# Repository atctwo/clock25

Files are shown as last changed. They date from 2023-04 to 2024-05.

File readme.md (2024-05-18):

# clock25
A funky digital clock made out of an ESP32 and an RGB LED matrix panel!  This was created as a one-off personal project, but all the code and design files are included so I hope you find it useful or interesting!

Picture of the front of the clock

## Features
- tells the time in big rainbow digits
- gets time from the internet using NTP, and has an onboard RTC for keeping time without power
- the time can also be configured using physical onboard buttons 
- supports multiple "screens" which are basically apps
- the system and each screen can be configured with a web interface
    - available at a custom URL using mDNS: [clock25.local](http://clock25.local)
- the configuration is stored on an SD card so it can be edited manually without internet 
- adaptive brightness using ambient light sensor

Currently implemented screens are
- **Digital Clock Face**: also shows current temperature and humidity if an SHTC3 is connected
- **Weather Forecast**: gets weather from the internet
- **GIF Player**:  plays GIFs from SD card

# Implementation
## Hardware
### HUB75 RGB LED matrix
The clock has a big HUB75-style RGB LED matrix panel.  I used one which has 64x64 pixels.

### Custom PCB
Picture of the PCB

The project is driven by a custom PCB.  It holds:
- an ESP32-S3
- a PCF8523 RTC and a CR2032 coin cell battery holder
- a microSD card slot for storing the config file (and GIFs)
    - [an SHTC3 temperature sensor](https://www.adafruit.com/product/4636)
    - [a VEML7700 ambient light sensor](https://www.adafruit.com/product/4162)
    - [a APDS9960 gesture sensor](https://www.adafruit.com/product/3595)
- a 2x10 0.1" header for connecting to the HUB75 panel
- a USB-C connector for power (5V, 3A)
- onboard buttons for setting the time or changing screen

It's made with KiCad and located in the [pcb](./pcb/) folder.

### 3D Printed Frame
Picture of the back of the clock

The project includes a 3D printed frame which holds the matrix and the PCB.  Although the assembled version uses a JLCPCB box superglued onto a minimal frame because I didn't have enough filament to print the whole frame.  Note that the frame is designed to fit the obscure shape of the panel I have, if you want to make a clock25 you might need to modify the OpenSCAD file to fit the dimensions of your panel.

It's written in OpenSCAD using the [MCAD](https://github.com/openscad/MCAD) library, and is located in the [frame](./frame/) folder

## Software
### Configuration System
When screens are registered at compile time, they specify a series of key-value configuration items.  For example, the Digital Clock Face has a setting called "Rainbow Speed" which determines the speed of the rainbow text animation.  Values for each setting are stored in memory.  If an SD card is mounted, when settings are overwritten they are stored in a JSON file on the SD card.  When the clock boots it will load saved values from the SD card.  Each setting can be modified from the web interface without rebooting the clock.

A sample config JSON file is located at [extras/sd_layout/settings.json](extras/sd_layout/settings.json).

### Recommended SD card layout
Different parts of the system depend on some files being at specific locations on the SD card:
- Files for the Web Interface are hosted from /web/
- Weather Forecast expects weather icons to be located at /weather/
- GIF Player loads gifs from /gifs/

As such, there is a recommended layout for the SD card:

```plain
.
├── gifs
│   ├── example.gif
├── settings.json
├── weather
│   ├── 01d.bmp
│   ├── 01n.bmp
│   ├── ...
│   └── 50n.bmp
└── web
    ├── ball.css
    ├── index.css
    ├── index.html
    └── index.js
```

This layout is provided at [extras/sd_layout](extras/sd_layout/), so if you're setting up the SD card you can just copy the contents of this folder to the root of the SD.

### Web Interface
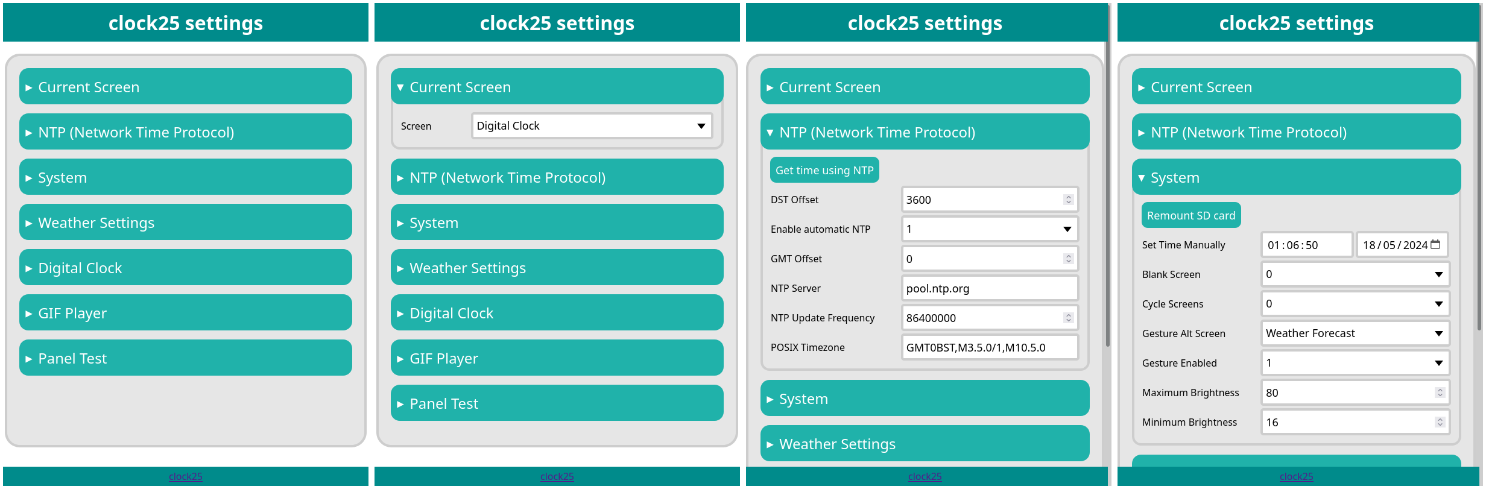
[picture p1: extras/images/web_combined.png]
Four screenshots of the web interface, showing the list of sections, and the screen, NTP, and system settings


When connected to a network, the clock provides a web interface for configuring the system and each screen.  It's hosted on port 80.  The clock announces a custom URL using mDNS: [clock25.local](http://clock25.local).

### Building
The project is built using PlatformIO, so make sure this is installed before building.  The project is designed for the ESP32-S3 using the Arduino framework, although it uses a lot of ESP32-specific function calls.

To build the code, open the project in VSCode.  PlatformIO should automatically initialise and will automatically download any required dependancies and libraries.  Go to the PlatformIO tab and click on Upload and Monitor.

# Credits
## Code Libraries
- [AnimatedGIF](https://github.com/bitbank2/AnimatedGIF) library for loading and displaying animated GIFs
- [AdafruitGFX](https://github.com/adafruit/Adafruit-GFX-Library) - graphics primitives used for the display
- [ESP32 HUB75 Matrix Panel DMA](https://github.com/mrcodetastic/ESP32-HUB75-MatrixPanel-DMA) for displaying graphics on the HUB75 matrix using DMA
- [Adafruit VEML7700 Library](https://github.com/adafruit/Adafruit_VEML7700) for the VEML7700 ambient light sensor
- [Adafruit APDS9960 Library](https://github.com/adafruit/Adafruit_APDS9960) for the APDS9960 gesture sensor
- [Adafruit SHTC3 Library](https://github.com/adafruit/Adafruit_SHTC3) for the SHTC3 temperature and humidity sensor
- [RTClib](https://github.com/adafruit/RTClib) for interfacing with the PCF8523 real time clock
- [Adafruit BusIO](https://github.com/adafruit/Adafruit_BusIO) I2C abstractions for Adafruit's sensor libraries
- [Adafruit Unified Sensor Library](https://github.com/adafruit/Adafruit_Sensor) common defines for Adafruit's sensor libraries
- [AdafruitJSON](https://github.com/bblanchon/ArduinoJson) library for serialisation/deserialisation of JSON documents
- Image loading using [stb_image](https://github.com/nothings/stb/blob/master/stb_image.h) by nothings
- OpenSCAD [MCAD](https://github.com/openscad/MCAD) library is used in the frame

## Assets
- Weather icons by [Royyan Wijaya](https://www.flaticon.com/packs/weather-1050)
- Fonts used are [Varela Round](https://fonts.google.com/specimen/Varela+Round) and [Open Sans](https://fonts.google.com/specimen/Open+Sans?query=open+sans)

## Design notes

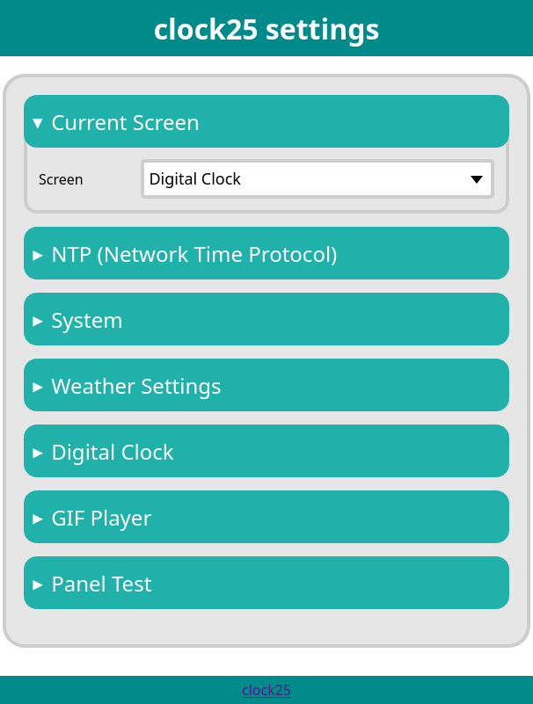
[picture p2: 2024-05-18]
extras/images/web_screen.png

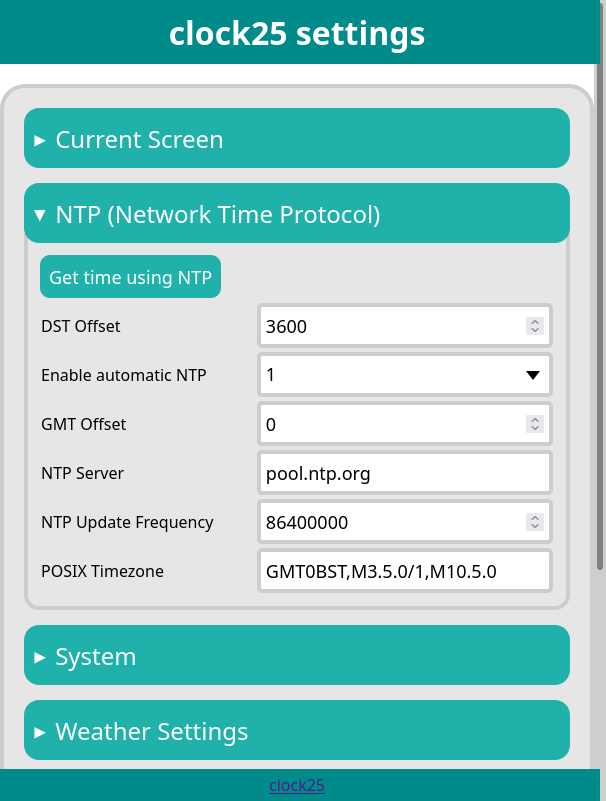
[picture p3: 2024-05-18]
extras/images/web_ntp.png

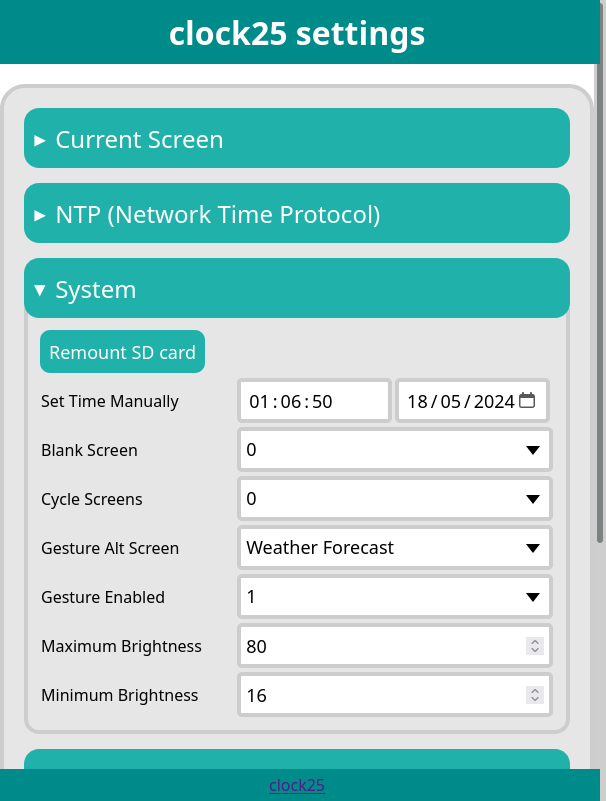
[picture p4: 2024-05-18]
extras/images/web_system.png

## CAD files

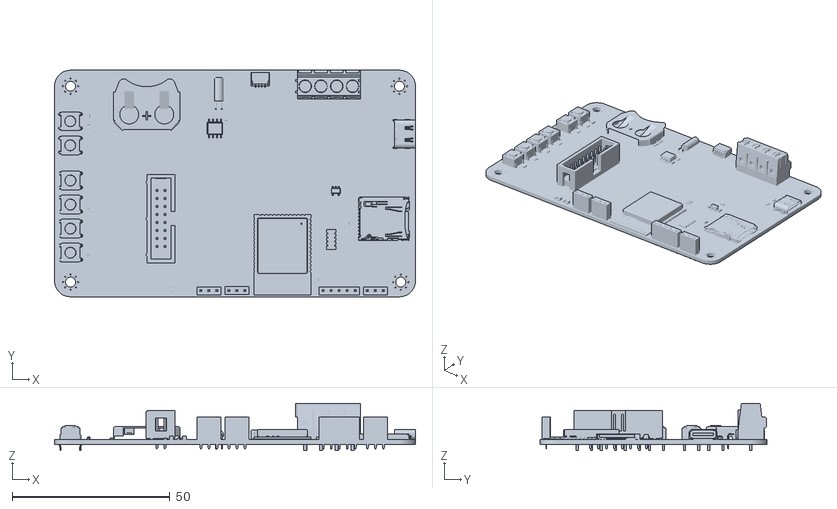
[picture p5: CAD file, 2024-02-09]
frame/clock25_board.stl
114.3 x 71.8 x 15.0

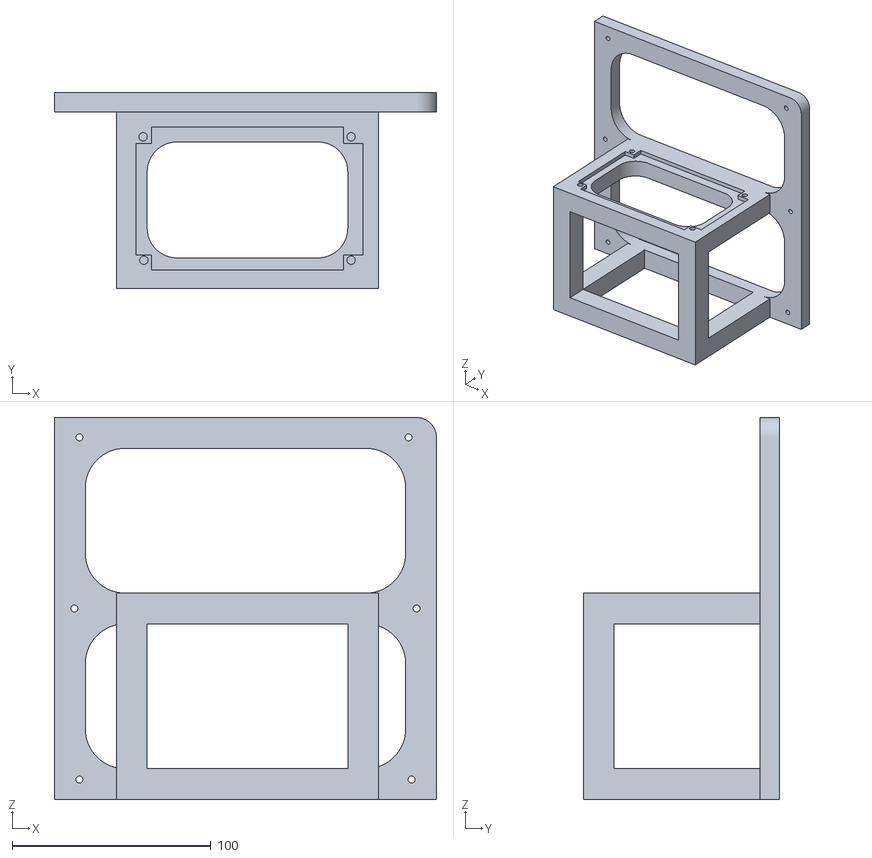
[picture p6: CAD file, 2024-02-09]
frame/clock25_frame.stl
192.0 x 98.8 x 192.0

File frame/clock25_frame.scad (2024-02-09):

/*
    clock25 frame
    
    by atctwo
    version 1
*/

use <MCAD/boxes.scad>

hub75_w = 192;
hub75_h = 192;
mh_corner_dx = 12.5;
mh_corner_dy = 10;
mh_middle_dx = 10;
mh_middle_dy = 10;
mh_d = 3.5;
cutout_radius = 20;
frame_width = 15.5;
frame_thickness = 10;

board_w = 114.3;
board_h = 71.755;
board_mh_dxy = 5.08;        // distance from middle of hole to edge of board
board_mh_d = 4.2;
board_mh_h = 5.4;
board_shell_padding = 1;
frame_board_spacing = 15;
thingy_r = 5;
inside_thingy_r = 15;
long_hole_width = 5;
long_hole_height = 3;
show_board = false;

$fn = 100;

// bit to hold board

arm_height = (hub75_h / 2) - (frame_width / 2);
block_w = board_w + (board_shell_padding * 2);
block_d = board_h + (board_shell_padding * 2) + frame_board_spacing;
block_middle_x =  (block_w / 2) + (frame_width/2);
block_middle_y = -(block_d / 2) + (frame_width/2) - frame_board_spacing;

translate([(hub75_w/2) - (board_w/2) - (frame_width/2), 0, 0])
{
    difference() {
        
        // main cube body
        union() {
                   
            // feet
            translate([0, -block_d, 0])
            cube([frame_width, block_d, frame_width]);
            
            translate([block_w, -block_d, 0])
            cube([frame_width, block_d, frame_width]);
            
            translate([0, -block_d, 0])
            cube([block_w, frame_width, frame_width]);
            
            // arms
            translate([0, -block_d, arm_height])
            cube([frame_width, block_d, frame_width]);
            
            translate([block_w, -block_d, arm_height])
            cube([frame_width, block_d, frame_width]);
            
            translate([0, -block_d, arm_height])
            cube([block_w, frame_width, frame_width]);
            
            // legs
            translate([0, -block_d, 0])
            cube([frame_width, frame_width, arm_height]);
            
            translate([block_w, -block_d, 0])
            cube([frame_width, frame_width, arm_height]);
            
            // big rounded bit in the middle
            difference() {
                translate([frame_width, -block_d+frame_width, arm_height])
                cube([
                    block_w - frame_width,
                    block_d - frame_width,
                    frame_width
                ]);
                    
                translate([frame_width, -block_d+frame_width, arm_height-0.1])
                roundedCube([
                        block_w - frame_width,
                        block_d - frame_width - frame_board_spacing,
                        frame_width+1
                    ], inside_thingy_r, true);
            }
        }
        
        // mounting holes
        
        // bottom left
        translate([
            block_middle_x - (board_w/2) + board_mh_dxy, 
            block_middle_y - (board_h/2) + board_mh_dxy + 8, 
            arm_height+frame_width-board_mh_h+0.001
        ]) cylinder(d=board_mh_d, h=board_mh_h+1.5);
        
        // top left
        translate([
            block_middle_x - (board_w/2) + board_mh_dxy - 0.4, 
            block_middle_y + (board_h/2) + board_mh_dxy - 1.7, 
            arm_height+frame_width-board_mh_h+0.001
        ]) cylinder(d=board_mh_d, h=board_mh_h+1.5);
        
        // bottom right
        translate([
            block_middle_x + (board_w/2) - board_mh_dxy, 
            block_middle_y - (board_h/2) + board_mh_dxy + 8, 
            arm_height+frame_width-board_mh_h+0.001
        ]) cylinder(d=board_mh_d, h=board_mh_h+1.5);
        
        // top right
        translate([
            block_middle_x + (board_w/2) - board_mh_dxy, 
            block_middle_y + (board_h/2) + board_mh_dxy - 1.7, 
            arm_height+frame_width-board_mh_h+0.001
        ]) cylinder(d=board_mh_d, h=board_mh_h+1.5);
        
        // long holes
        
        // west
        translate([
            block_middle_x - (board_w/2) + 1, 
            block_middle_y - (board_h/2) + (board_mh_dxy * 3.1), 
            arm_height+frame_width-long_hole_height
        ]) cube([board_w, board_h - (board_mh_dxy*3.1), long_hole_height+1]);
        
        // south
        translate([
            block_middle_x - (board_w/2) + long_hole_width*1.8, 
            block_middle_y - (board_h/2) + (board_mh_dxy * 3.1) - (long_hole_width*1.5), 
            arm_height+frame_width-long_hole_height
        ]) cube([board_w - (board_mh_dxy*3.5), board_h, long_hole_height+1]);
    }
    
    if (show_board) {
        color("darkcyan", 0.3)
        translate([
            (89.9 + board_w) + (frame_width/2),
            (-64.77-board_h) - (frame_width/2), 
            arm_height+frame_width
        ]) rotate([0, 0, 180])
        import("clock25_board.stl");
    }
}

/*
cube_w = board_w + (board_shell_padding * 2);
cube_d = board_h + (board_shell_padding * 2) + frame_board_spacing;
cube_h = (hub75_h / 2) + (frame_width / 2);
    
translate([(hub75_w/2) - (board_w/2), -cube_d, 0])
difference() {
    
    union() {
        
        // main cube
        roundedCube([cube_w, cube_d, cube_h], thingy_r);
        
        // flat bit at top
        translate([0, 0, cube_h - frame_width])
        roundedCube([cube_w, cube_d + frame_thickness, frame_width], thingy_r, true);
    }
    
    // holes
    translate([-2.5, frame_width, frame_width])
    roundedCube([cube_w+5, cube_d - (frame_width * 2), cube_h - (frame_width * 2)], thingy_r);
    
    translate([frame_width, -2.5, frame_width])
    roundedCube([cube_w - (frame_width * 2), cube_d + 5, cube_h - (frame_width * 2)], thingy_r);
    
    translate([frame_width, frame_width, -2.5])
    roundedCube([cube_w - (frame_width * 2), cube_d - (frame_width * 2), cube_h + 5], thingy_r);
    
}
*/

// frame to hold hub75
difference() {
    
    // main frame body
    union() {
        translate([0, frame_thickness, 0])
        rotate([90, 0, 0])
        roundedCube([hub75_w, hub75_h, frame_thickness], 10, true);
        
        // bottom left
        cube([hub75_w/2, frame_thickness, hub75_h/2]);
        
        // bottom right
        translate([hub75_w - (hub75_w/2), 0, 0])
        cube([hub75_w/2, frame_thickness, hub75_h/2]);
        
        // top left
        translate([0, 0, hub75_h - (hub75_h/2)])
        cube([hub75_w/2, frame_thickness, hub75_h/2]);
    }
    
    // mounting hole holes
    
    // bottom left
    translate([mh_corner_dx, -0.1, mh_corner_dy])
    hole(mh_d, frame_thickness+1);
    
    // bottom right
    translate([hub75_w - mh_corner_dx, -0.1, mh_corner_dy])
    hole(mh_d, frame_thickness+1);
    
    // top left
    translate([mh_corner_dx, -0.1, hub75_h - mh_corner_dy])
    hole(mh_d, frame_thickness+1);
    
    // top right
    translate([hub75_w - mh_corner_dx - 1.5, -0.1, hub75_h - mh_corner_dy])
    hole(mh_d, frame_thickness+1);
    
    // middle left
    translate([mh_middle_dx, -0.1, (hub75_h/2)])
    hole(mh_d, frame_thickness+1);
    
    // middle right
    translate([hub75_w - mh_middle_dx, -0.1, (hub75_h/2)])
    hole(mh_d, frame_thickness+1);
    
    // big cutouts
    cutout_w = hub75_w - (frame_width * 2);
    cutout_h = (hub75_h / 2) - (frame_width * 1.5);
    
    translate([frame_width, -0.5, frame_width])
    roundedCube([
        cutout_w,
        frame_thickness + 1,
        cutout_h
    ], cutout_radius);
    
    translate([frame_width, -0.5, (frame_width*2) + cutout_h])
    roundedCube([
        cutout_w,
        frame_thickness + 1,
        cutout_h
    ], cutout_radius);
}

// hole
module hole(d, h) {
    rotate([270, 0 ,0])
    cylinder(d=d, h=h);
}

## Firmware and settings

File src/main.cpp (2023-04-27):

#include <Arduino.h>
#include "pins.h"
#include "display.h"
#include "brightness.h"
#include "sensors.h"
#include "button.h"
#include "rtc.h"
#include "gesture.h"
#include "settings.h"
#include "sd.h"
#include "wifi.h"
#include "ntp.h"
#include "server.h"
#include "screens/screens.h"
#include "log.h"
#include <SPIFFS.h>

#define LOG_TAG "main"

uint32_t last_switch_time = 0;
uint32_t last_brightness_time = 0;
uint32_t last_random_time = 0;
bool screen_blanked = 0;
uint8_t last_brightness = get_brightness();

uint32_t last_ntp_update = 0;
uint32_t ntp_update_frequency = 0;
bool enable_automatic_ntp = true;

uint32_t last_gesture_check = 0;
uint32_t gesture_check_frequency = 0;

int next_screen = 0;
int cycle_screens = 0;

void set_cycle_screens(std::string new_value) {
    cycle_screens = std::stoi(new_value.c_str());
}

void set_ntp_update_frequency(std::string new_value) {
    last_ntp_update = millis(); // reset ntp timer
    ntp_update_frequency = std::stoi(new_value.c_str());
}

void set_automatic_ntp_update(std::string new_value)
{
    enable_automatic_ntp = std::stoi(new_value.c_str());
}

void set_screen_blanked(std::string new_value)
{
    screen_blanked = std::stoi(new_value);

    if (screen_blanked) {
        last_brightness = get_brightness();
        set_display_brightness(1);
    } else {
        set_display_brightness(last_brightness);
    }
}

void setup()
{
    delay(1000);
    Serial.begin(115200);
    USBSerial.begin(115200);

    logi(LOG_TAG, "clock25 starting!");

    // setup i2c
    Wire.begin(SDA_PIN, SCL_PIN);

    // setup SPI
    SPI.begin(SPI_SCK, SPI_MISO, SPI_MOSI);

    // setup spiffs
    if (!SPIFFS.begin()) loge(LOG_TAG, "failed to init spiffs");

    // setup display and peripherals
    setup_display();
    setup_brightness();
    setup_buttons();
    setup_sensors();
    setup_rtc();
    setup_sd();

    // setup screen subsystem and settings
    setup_screens();
    register_setting_callback("<system>", "Cycle Screens", set_cycle_screens);
    register_setting_callback("<system>", "Blank Screen", set_screen_blanked);
    register_setting_callback("<ntp>", "NTP Update Frequency", set_ntp_update_frequency);
    register_setting_callback("<ntp>", "Enable automatic NTP", set_ntp_update_frequency);
    set_setting_values("<system>", "Cycle Screens", {"0", "1"});
    set_setting_values("<system>", "Blank Screen", {"0", "1"});
    set_setting_values("<ntp>", "Enable automatic NTP", {"0", "1"});

    // setup gesture (after screens so it can use screens to set setting values)
    setup_gesture();

    // load settings from sd card
    if (sd_available()) load_settings(SD);
    else logi(LOG_TAG, "Can't derserialise settings from SD because SD isn't available");
    
    // setup wifi
    setup_wifi();
    connect_wifi([](){
        // only do these thing when wifi is connected
        get_time_from_ntp();
        setup_ntp_server();
        setup_http_server();
    });

    // start!
    switch_screen(0);
    set_display_brightness(128);
}

void loop()
{
    update_screen(display);
    update_fade();

    // handle server requests
    server_handle_client();

    // cycle screens
    if (cycle_screens)
    {
        if (millis() - last_switch_time > 5000)
        {
            next_screen++;
            if (next_screen >= screens.size()) next_screen = 0;

            switch_screen(next_screen);

            last_switch_time = millis();
        }
    }

    // update brightness
    if (!screen_blanked)
    {
        if (millis() - last_brightness_time > 500) {
            if (brightness_available()) {

                set_display_brightness(get_brightness());
                last_brightness_time = millis();

            } else set_display_brightness(128);
        }
    }

    // ntp update
    if (enable_automatic_ntp && ntp_update_frequency != 0) {
        if (millis() - last_ntp_update > ntp_update_frequency) {
            get_time_from_ntp();
            last_ntp_update = millis();
        }
    }

    // check gesture
    if (millis() - last_gesture_check > gesture_check_frequency)
    {
        check_gesture();
        last_gesture_check = millis();
    }

    // check buttons
    check_buttons();

    // randomise rainbow speed
    // if (millis() - last_random_time > 2500)
    // {
    //     uint16_t new_speed = 1 + rand() % 1000;
    //     set_setting("Digital Clock", "Rainbow Speed", std::to_string(new_speed).c_str());
    //     last_random_time = millis();
    // }

    // change gif
    // if (millis() - last_random_time > 2500)
    // {
    //     uint16_t new_gif = rand() % 5;

    //     switch(new_gif) {
    //         case 0:
    //             set_setting("GIF Player", "GIF File", "/gifs/amogus64.gif");
    //             break;
    //         case 1:
    //             set_setting("GIF Player", "GIF File", "/gifs/dipp.gif");
    //             break;
    //         case 2:
    //             set_setting("GIF Player", "GIF File", "/gifs/kirby.gif");
    //             break;
    //         case 3:
    //             set_setting("GIF Player", "GIF File", "/gifs/puppycat.gif");
    //             break;
    //         case 4:
    //             set_setting("GIF Player", "GIF File", "/gifs/squid.gif");
    //             break;
    //     }

    //     last_random_time = millis();
    // }
}

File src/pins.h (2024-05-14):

#ifndef CLOCK_PINS_H
#define CLOCK_PINS_H


// whether to include test screens
// #define INCLUDE_TEST_SCREENS

// which filesystem to use
#define FILESYSTEM SD
// #define FILESYSTEM SPIFFS

// buffer size for ArduinoJson
#define JSON_BUFFER_SIZE 4096
#define JSON_DYNAMIC_BUFFER_SIZE 24576
#define SETTINGS_FILE "/settings.json"

// buttons
#define BTN_HOUR 13
#define BTN_MINUTE 14
#define BTN_SCREEN 21
#define BTN_REVERSE 47

// I2C pins
#define SDA_PIN 12
#define SCL_PIN 11

// SPI pins
#define SPI_MISO 10
#define SPI_MOSI 9
#define SPI_SCK 46
#define SPI_SD_CS 17


// LED matrix pins

#define R1_PIN 4
#define G1_PIN 5
#define B1_PIN 6
#define R2_PIN 7
#define G2_PIN 15
#define B2_PIN 16
#define A_PIN  18
#define B_PIN  8
#define C_PIN  3
#define D_PIN  42
#define E_PIN  39 // required for 1/32 scan panels, like 64x64. Any available pin would do, i.e. IO32
#define LAT_PIN 40
#define OE_PIN  2
#define CLK_PIN 41

#define PANEL_RES_X 64     // Number of pixels wide of each INDIVIDUAL panel module. 
#define PANEL_RES_Y 64     // Number of pixels tall of each INDIVIDUAL panel module.
#define PANEL_CHAIN 1      // Total number of panels chained one to another

#endif /* CLOCK_PINS_H */

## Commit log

2023-03-25 gif player bug fixes
    [gifplayer.cpp]
2023-03-26 gif player: fixed bug when reloading screen
    [gifplayer.cpp]
2023-03-26 settings: fixed sd load dangling pointer originally, when loading from sd, it would populate the settings map using c strings from the deserialised json document. this would copy a pointer to the str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
    [main.cpp]
2023-03-26 added arduinojson dependancy
2023-04-01 added fading between screens when switching
2023-04-01 brightness: fixed automatic brightness
    [main.cpp]
2023-04-02 clock face: fixed month display it was showing the month as one month earlier than it actually was
    [ntp.cpp]
2023-04-06 screens: updated switch_screen return type also, reset font and cursor position on switch screen
2023-04-16 sd: added sample settings.json
2023-04-27 web: added button to remount sd card
2023-04-27 button: added button control to adjust time and screen without wifi
2023-04-29 pcb: added schematic and pcb
    [clock25-B_Cu.gbr, clock25-B_Mask.gbr, clock25-B_Paste.gbr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]
2024-02-09 added frame
    [clock25_board.stl, clock25_frame.scad, clock25_frame.stl]
2024-02-09 updated pcb
    [clock25-B_Cu.gbr, clock25-B_Mask.gbr, clock25-B_Paste.gbr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]
2024-05-15 panel test: use nullptr for current screen name for settings
